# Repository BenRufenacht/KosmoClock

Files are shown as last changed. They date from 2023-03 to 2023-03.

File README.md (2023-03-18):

# KosmoClock
 Kosmo Format Clock Module based on LittleBen by Quinie 

 <p align="center">
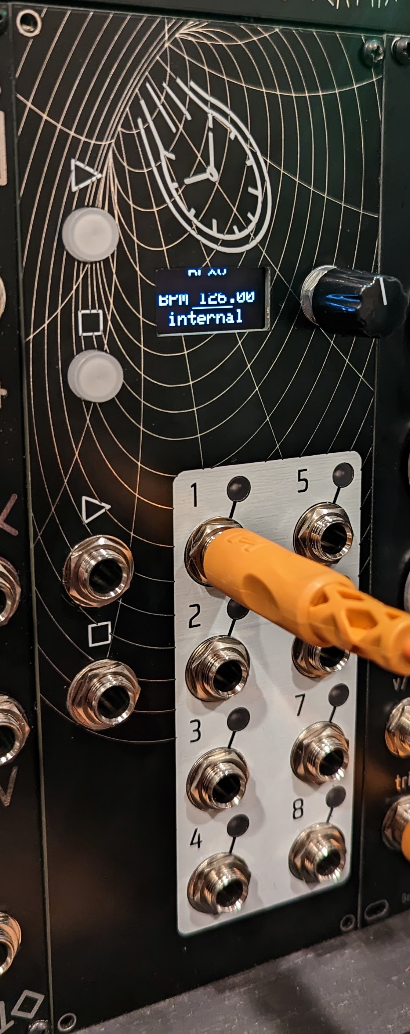
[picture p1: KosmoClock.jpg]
Kosmo Clock
  
</p>

Note that the UI varies significantly from Quinie's version.

Status:   
February 2023 - First run of manufacturing found some minor mistakes that were fixed, but the updates to the main board have not been tested.

License:  
[CC-BY-SA](https://creativecommons.org/licenses/by-sa/3.0/)

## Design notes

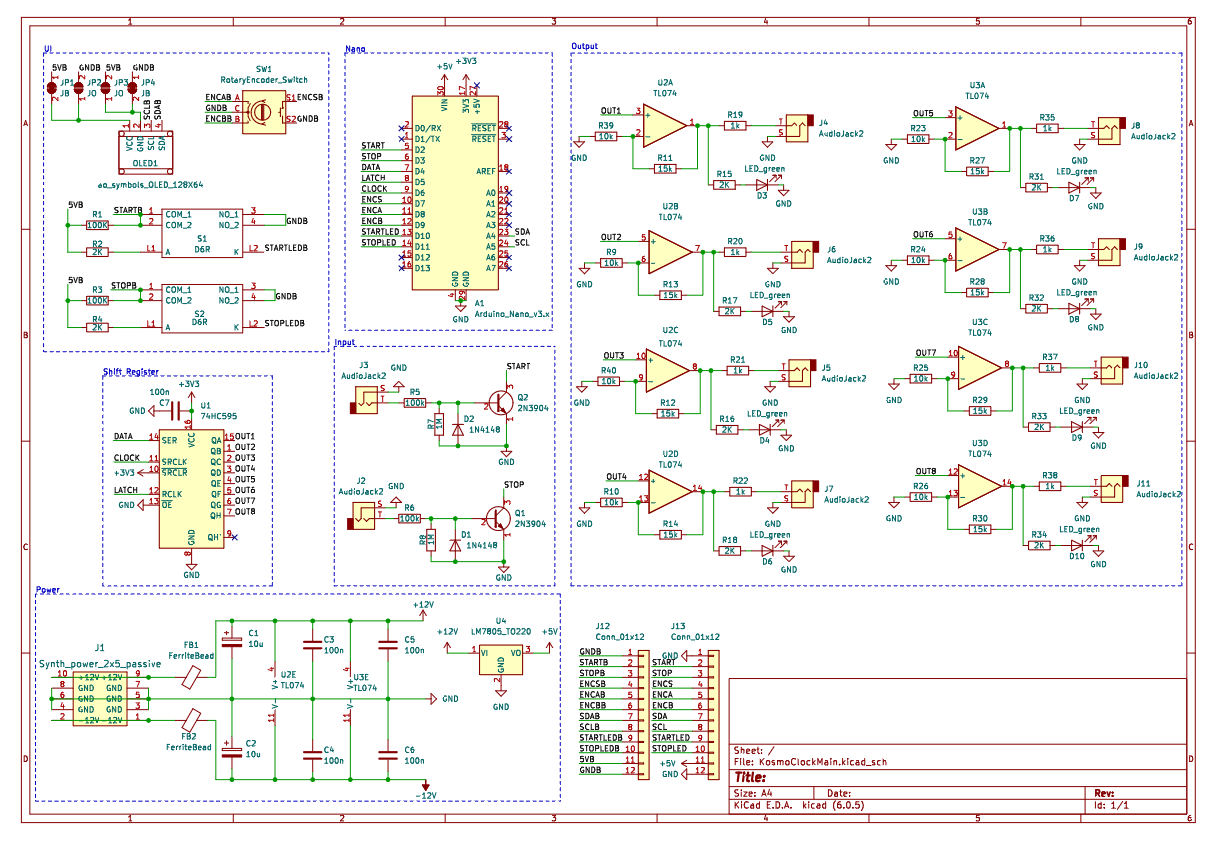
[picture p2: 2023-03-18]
ClockSchematics.png

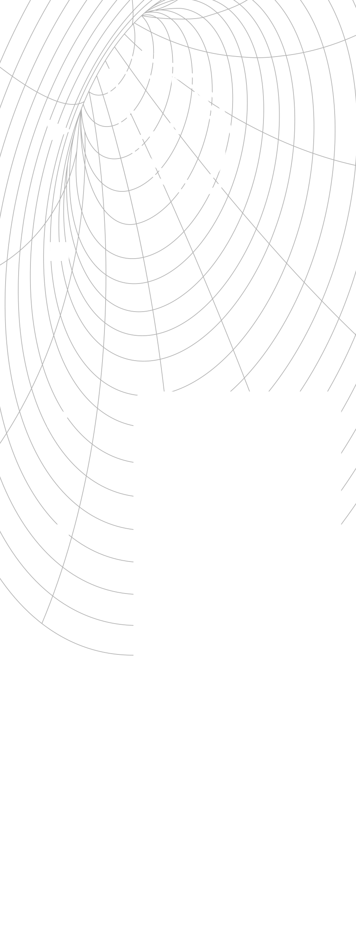
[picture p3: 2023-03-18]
ClockPanelTin.png

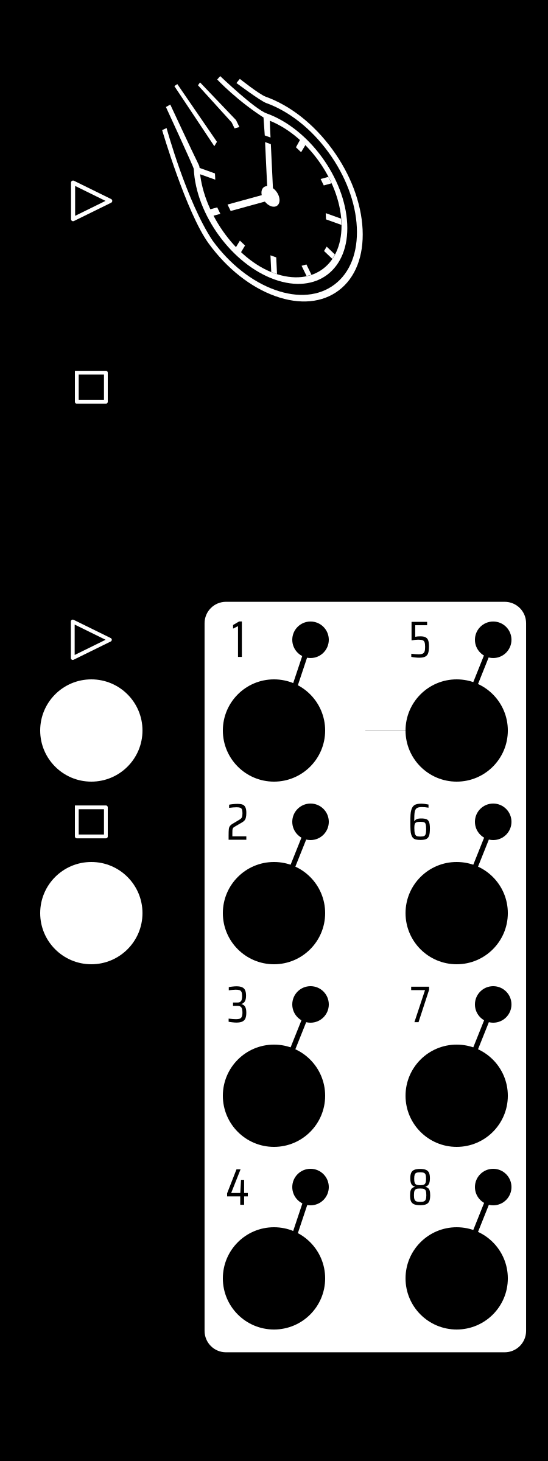
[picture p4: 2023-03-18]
ClockPanelSilkscreen.png

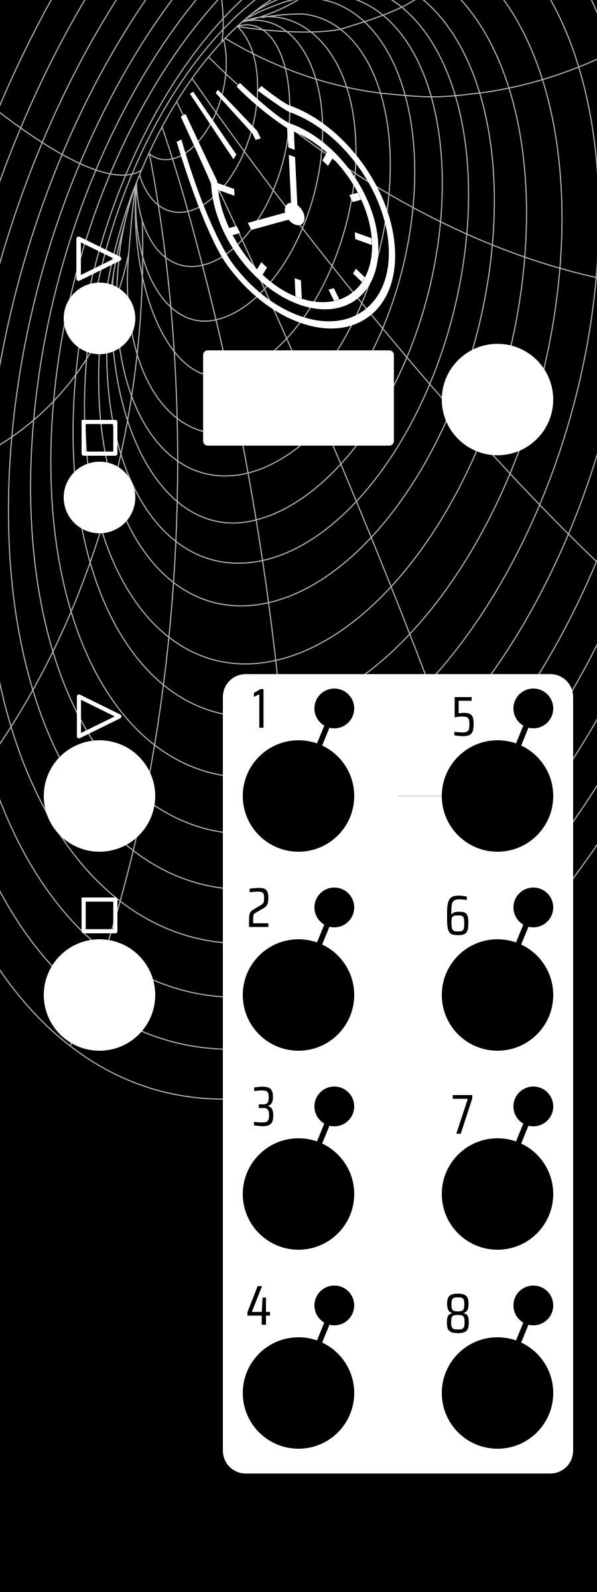
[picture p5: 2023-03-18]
ClockPanelGraphics.png

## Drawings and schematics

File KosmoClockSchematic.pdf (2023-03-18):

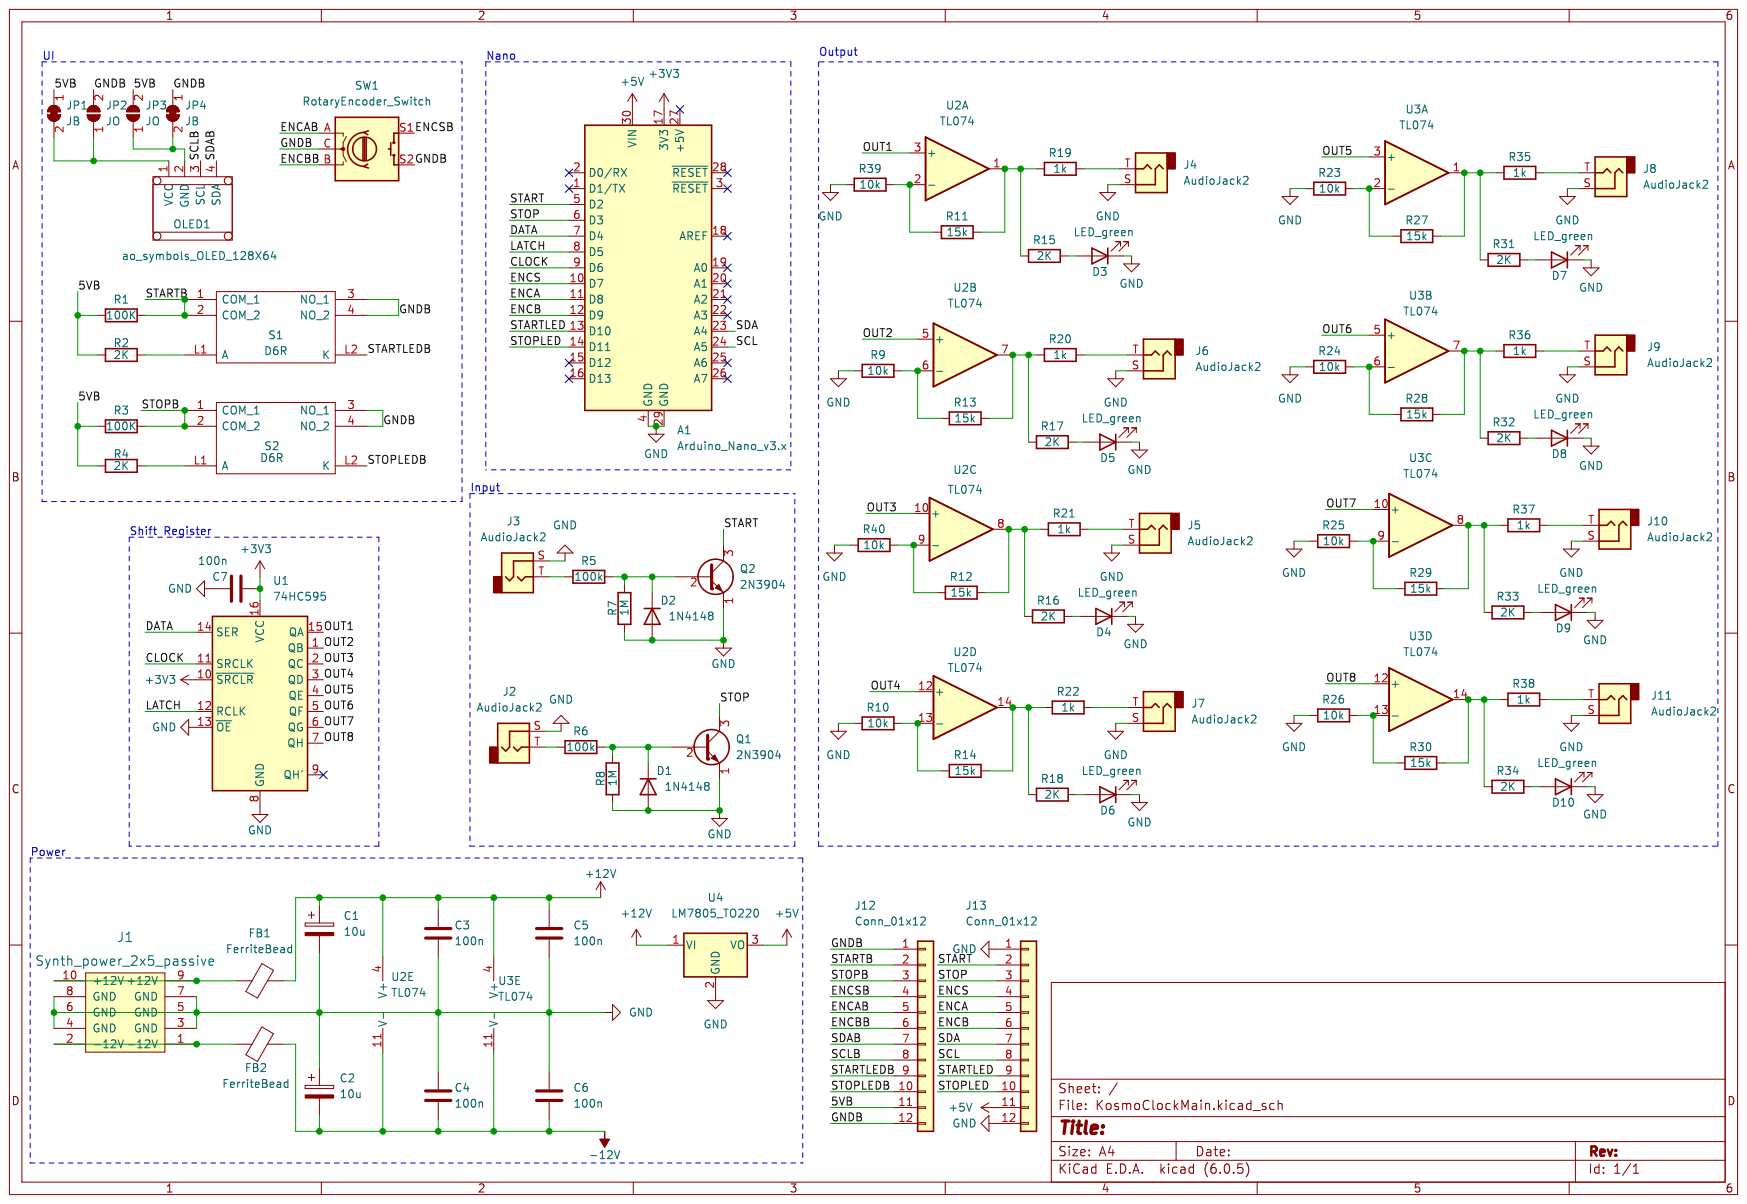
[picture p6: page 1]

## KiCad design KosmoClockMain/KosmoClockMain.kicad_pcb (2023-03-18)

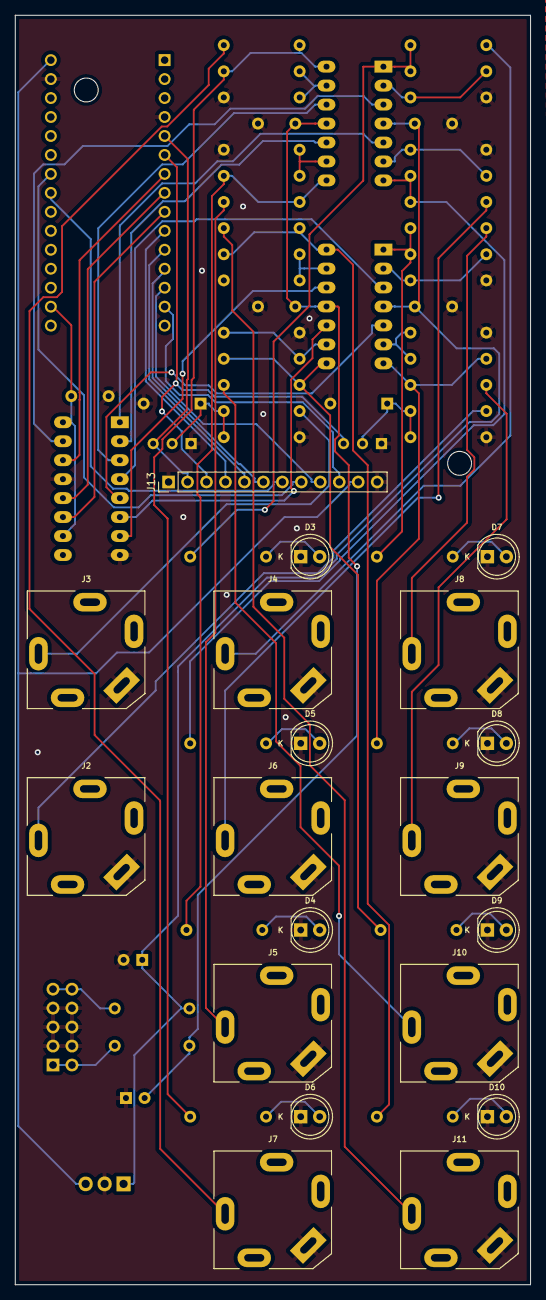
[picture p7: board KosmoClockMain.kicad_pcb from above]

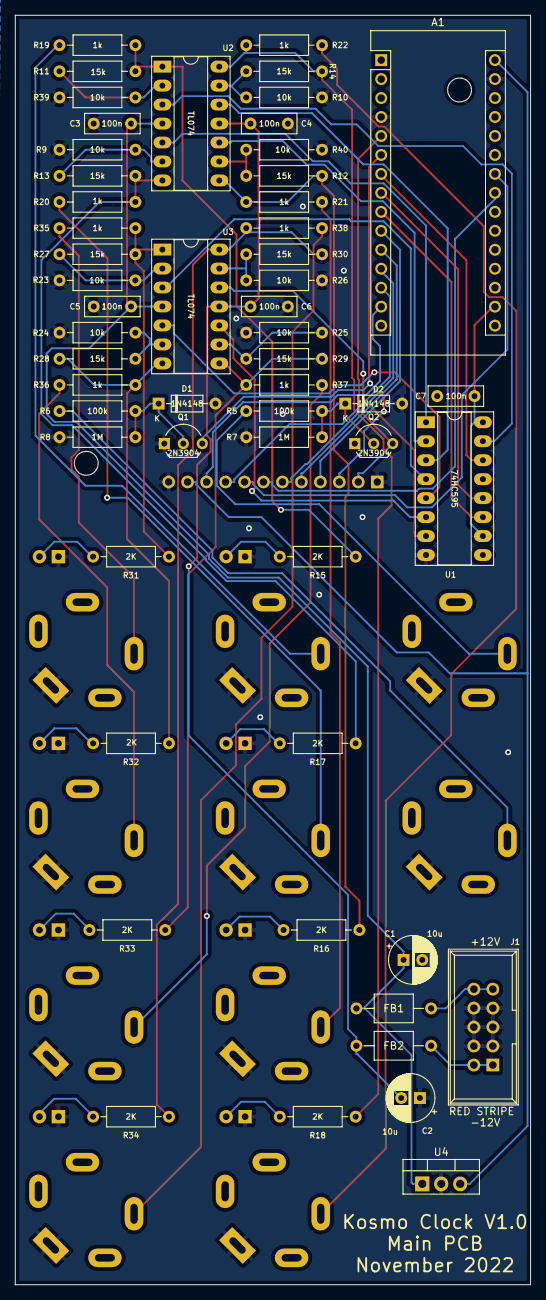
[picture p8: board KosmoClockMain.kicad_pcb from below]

Board: 2 copper layers, 69.0 x 170.0 mm, 74 parts (55 on the bottom side), 63 nets.

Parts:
A1: Arduino_Nano_v3.x; Arduino_Nano
C1, C2: 10u; CP_Radial_D6.3mm_P2.50mm
C3, C4, C5, C6, C7: 100n; C_Rect_L7.2mm_W2.5mm_P5.00mm_FKS2_FKP2_MKS2_MKP2
D1, D2: 1N4148; D_DO-35_SOD27_P7.62mm_Horizontal
D3, D4, D5, D6, D7, D8, D9, D10: LED_green; LED_D5.0mm
FB1, FB2: FerriteBead; L_Axial_L5.0mm_D3.6mm_P10.00mm_Horizontal_Murata_BL01RN1A2A2
J1: Synth_power_2x5_passive; Power_Header
J2, J3, J4, J5, J6, J7, J8, J9, J10, J11: AudioJack2; Jack_6.35mm_PJ_629HAN_slots
J13: Conn_01x12; PinHeader_1x12_P2.54mm_Vertical
Q1, Q2: 2N3904; TO-92_Inline_Wide
R5, R6: 100k; R_Axial_DIN0207_L6.3mm_D2.5mm_P10.16mm_Horizontal
R7, R8: 1M; R_Axial_DIN0207_L6.3mm_D2.5mm_P10.16mm_Horizontal
R9, R10, R23, R24, R25, R26, R39, R40: 10k; R_Axial_DIN0207_L6.3mm_D2.5mm_P10.16mm_Horizontal
R11, R12, R13, R14, R27, R28, R29, R30: 15k; R_Axial_DIN0207_L6.3mm_D2.5mm_P10.16mm_Horizontal
R15, R16, R17, R18, R31, R32, R33, R34: 2K; R_Axial_DIN0207_L6.3mm_D2.5mm_P10.16mm_Horizontal
R19, R20, R21, R22, R35, R36, R37, R38: 1k; R_Axial_DIN0207_L6.3mm_D2.5mm_P10.16mm_Horizontal
U1: 74HC595; DIP-16_W7.62mm_Socket_LongPads
U2, U3: TL074; DIP-14_W7.62mm_Socket_LongPads
U4: LM7805_TO220; TO-220-3_Vertical

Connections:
+3V3: A1.17 (3V3), C7.2, U1.10 (~SRCLR), U1.16 (VCC)
+5V: A1.30 (VIN), J13.11, U4.3 (VO)
+12V: C1.1, C3.1, C5.1, FB1.2, U2.4 (V+), U3.4 (V+), U4.1 (VI)
-12V: C2.2, C4.1, C6.1, FB2.2, U2.11 (V-), U3.11 (V-)
/CLOCK: A1.9 (D6), U1.11 (SRCLK)
/DATA: A1.7 (D4), U1.14 (SER)
/ENCA: A1.11 (D8), J13.5
/ENCB: A1.12 (D9), J13.6
/ENCS: A1.10 (D7), J13.4
/LATCH: A1.8 (D5), U1.12 (RCLK)
/OUT1: U1.15 (QA), U2.3 (+)
/OUT2: U1.1 (QB), U2.5 (+)
/OUT3: U1.2 (QC), U2.10 (+)
/OUT4: U1.3 (QD), U2.12 (+)
/OUT5: U1.4 (QE), U3.3 (+)
/OUT6: U1.5 (QF), U3.5 (+)
/OUT7: U1.6 (QG), U3.10 (+)
/OUT8: U1.7 (QH), U3.12 (+)
/SCL: A1.24 (A5), J13.8
/SDA: A1.23 (A4), J13.7
/START: A1.5 (D2), J13.2, Q2.3 (C)
/STARTLED: A1.13 (D10), J13.9
/STOP: A1.6 (D3), J13.3, Q1.3 (C)
/STOPLED: A1.14 (D11), J13.10
GND: A1.4 (GND), A1.29 (GND), C1.2, C2.1, C3.2, C4.2, C5.2, C6.2, C7.1, D1.2 (A), D2.2 (A), D3.1 (K), D4.1 (K), D5.1 (K), D6.1 (K), D7.1 (K), D8.1 (K), D9.1 (K), D10.1 (K), J1.3 (GND), J1.4 (GND), J1.5 (GND), J1.6 (GND), J1.7 (GND), J1.8 (GND), J2.S, J3.S, J4.S, J5.S, J6.S, J7.S, J8.S, J9.S, J10.S, J11.S, J13.1, J13.12, Q1.1 (E), Q2.1 (E), R7.2, R8.2, R9.1, R10.1, R23.1, R24.1, R25.1, R26.1, R39.1, R40.1, U1.8 (GND), U1.13 (~OE), U4.2 (GND)
unnamed: D1.1 (K), Q1.2 (B), R6.2, R8.1
unnamed: D2.1 (K), Q2.2 (B), R5.2, R7.1
unnamed: D3.2 (A), R15.2
unnamed: D4.2 (A), R16.2
unnamed: D5.2 (A), R17.2
unnamed: D6.2 (A), R18.2
unnamed: D7.2 (A), R31.2
unnamed: D8.2 (A), R32.2
unnamed: D9.2 (A), R33.2
unnamed: D10.2 (A), R34.2
unnamed: FB1.1, J1.9 (+12V), J1.10 (+12V)
unnamed: FB2.1, J1.1 (-12V), J1.2 (-12V)
unnamed: J2.T, R6.1
unnamed: J3.T, R5.1
unnamed: J4.T, R19.2
unnamed: J5.T, R21.2
unnamed: J6.T, R20.2
unnamed: J7.T, R22.2
unnamed: J8.T, R35.2
unnamed: J9.T, R36.2
unnamed: J10.T, R37.2
unnamed: J11.T, R38.2
unnamed: R10.2, R14.1, U2.13 (-)
unnamed: R11.1, R39.2, U2.2 (-)
unnamed: R11.2, R15.1, R19.1, U2.1
unnamed: R12.1, R40.2, U2.9 (-)
unnamed: R12.2, R16.1, R21.1, U2.8
unnamed: R9.2, R13.1, U2.6 (-)
unnamed: R13.2, R17.1, R20.1, U2.7
unnamed: R14.2, R18.1, R22.1, U2.14
unnamed: R23.2, R27.1, U3.2 (-)
unnamed: R24.2, R28.1, U3.6 (-)
unnamed: R25.2, R29.1, U3.9 (-)
unnamed: R26.2, R30.1, U3.13 (-)
unnamed: R27.2, R31.1, R35.1, U3.1
unnamed: R28.2, R32.1, R36.1, U3.7
unnamed: R29.2, R33.1, R37.1, U3.8
unnamed: R30.2, R34.1, R38.1, U3.14

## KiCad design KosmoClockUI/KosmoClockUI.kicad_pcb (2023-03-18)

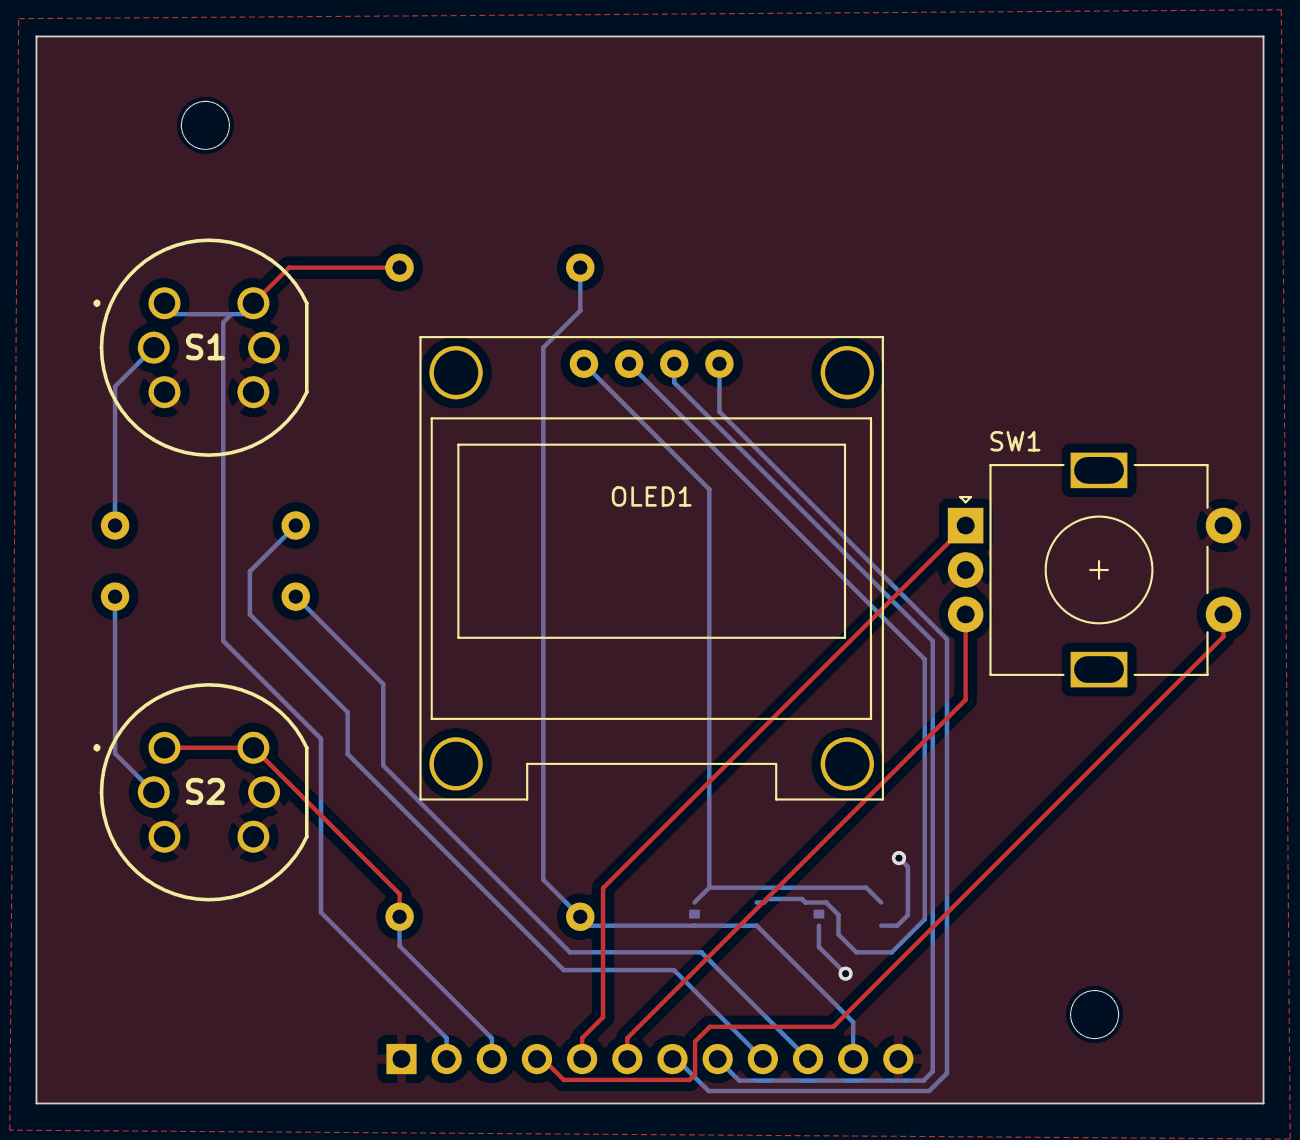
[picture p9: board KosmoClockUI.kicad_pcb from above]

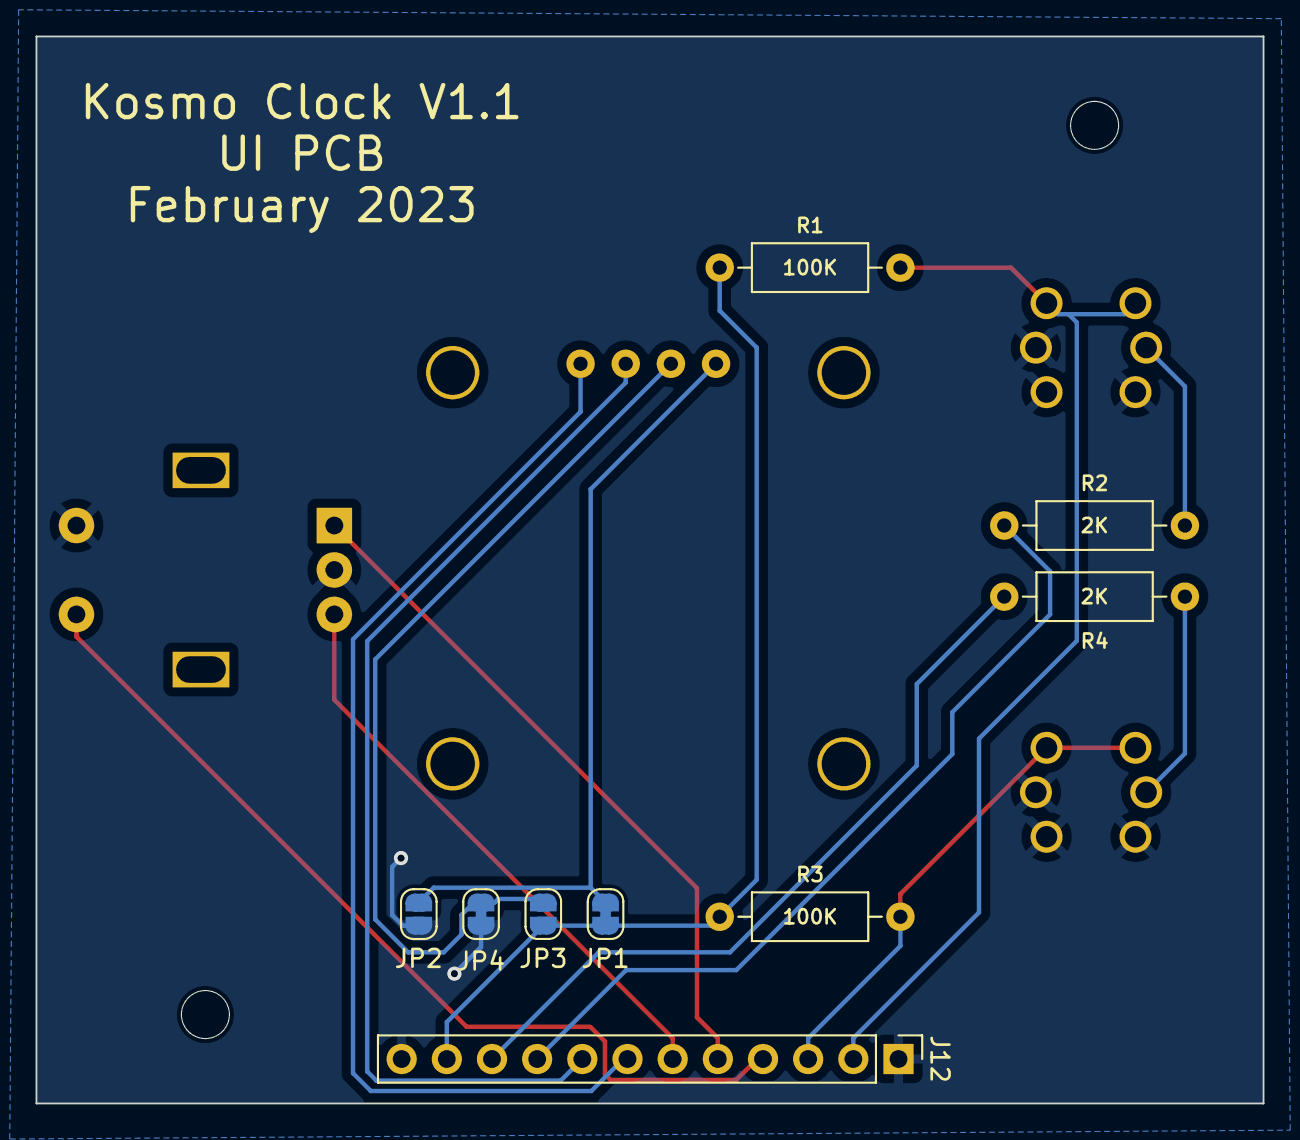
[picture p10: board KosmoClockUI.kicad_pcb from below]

Board: 2 copper layers, 69.0 x 60.0 mm, 13 parts (9 on the bottom side), 15 nets.

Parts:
J12: Conn_01x12; PinHeader_1x12_P2.54mm_Vertical
JP1, JP4: JB; SolderJumper-2_P1.3mm_Bridged_RoundedPad1.0x1.5mm
JP2, JP3: JO; SolderJumper-2_P1.3mm_Open_RoundedPad1.0x1.5mm
OLED1: ao_symbols_OLED_128X64; SSD1306_0.96_Oled
R1, R3: 100K; R_Axial_DIN0207_L6.3mm_D2.5mm_P10.16mm_Horizontal
R2, R4: 2K; R_Axial_DIN0207_L6.3mm_D2.5mm_P10.16mm_Horizontal
S1, S2: D6RLGNF1LFS
SW1: RotaryEncoder_Switch; RotaryEncoder_Alps_EC11E-Switch_Vertical_H20mm

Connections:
/5VB: J12.11, JP1.1 (A), JP3.2 (B), R1.1, R3.1
/ENCAB: J12.5, SW1.A
/ENCBB: J12.6, SW1.B
/ENCSB: J12.4, SW1.S1
/GNDB: J12.1, J12.12, JP2.2 (B), JP4.1 (A), S1.3 (NO_1), S1.4 (NO_2), S1.L2 (K), S2.3 (NO_1), S2.4 (NO_2), S2.L2 (K), SW1.C, SW1.S2
/SCLB: J12.8, OLED1.3 (SCL)
/SDAB: J12.7, OLED1.4 (SDA)
/STARTB: J12.2, R1.2, S1.1 (COM_1), S1.2 (COM_2)
/STARTLEDB: J12.9, R2.1
/STOPB: J12.3, R3.2, S2.1 (COM_1), S2.2 (COM_2)
/STOPLEDB: J12.10, R4.1
unnamed: JP1.2 (B), JP2.1 (A), OLED1.1 (VCC)
unnamed: JP3.1 (A), JP4.2 (B), OLED1.2 (GND)
unnamed: R2.2, S1.L1 (A)
unnamed: R4.2, S2.L1 (A)

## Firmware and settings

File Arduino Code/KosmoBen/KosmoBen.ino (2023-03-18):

/* 
 *  KosmoBen
 *  
 *  A master clock for Kosmo systems
 *  By: Ben Rufenacht
 *  Adapted From: Quinie.nl
 *  
 */

// Includes needed for running this code.
// TimerOne will handle the timing of the pulses

#include <TimerOne.h>  
#include <SPI.h>
#include <Wire.h>
#include <Adafruit_GFX.h>
#include <Adafruit_SSD1306.h>
#include <BasicEncoder.h>
#include <Bounce2.h>

#include "LittleBenOutputs.h"

int const maxLBOutput = 8;
// Load the outputs as class
LittleBenOutput LBOutputs[maxLBOutput] = {
  LittleBenOutput(0),
  LittleBenOutput(1),
  LittleBenOutput(2),
  LittleBenOutput(3),
  LittleBenOutput(4),
  LittleBenOutput(5),
  LittleBenOutput(6),
  LittleBenOutput(7)
};

byte selectedLBOutput = 0;

//Clock Settings
byte statusClock = 0; // 0 = stopped, 1 = playing, 2 = pause
byte clockSource = 1; // 0 = internal, 1 = external

long intervalMicroSeconds;  // variable for interval for timer running clock pulses calculted on BPM value

// These are used to output the clock on the 595 chip
// The bit are linked to the ouput as 2,4,6,8,1,3,5,7 <-- note: double check note sure
byte outputClockBits = B00000000; 

float bpm = 126;  // BPM value 
byte ppqn = 24; // Pulse per beat

#define startTriggerPin 2 // Start trigger pin
#define stopTriggerPin 3 // Stop trigger pin

// 595 output pins 
byte outputLatchPin = 5; 
byte outputClockPin = 6; 
byte outputDataPin = 4;  

// Rotary Encoder Inputs pins
#define inputCLK 9
#define inputDT 8
#define inputSW 7

BasicEncoder enc(inputCLK, inputDT);
Bounce2::Button SW = Bounce2::Button();

// Current en previous states of rotary pins
byte currentStateSW; 
byte previousStateSW;
byte currentStateEnc;
byte previousStateEnc; 

// Current menu item
byte menuItem = 0;

//Oled display settings
#define SCREEN_WIDTH 128 
#define SCREEN_HEIGHT 64
#define OLED_RESET     4 
#define SCREEN_ADDRESS 0x3C

int name;

bool updateScreen = false;
bool saving = false;
long savingtime;

Adafruit_SSD1306 display(SCREEN_WIDTH, SCREEN_HEIGHT, &Wire, OLED_RESET);

void setup() {

  // Set timer for internal clock
  Timer1.initialize(intervalMicroSeconds);
  Timer1.setPeriod(calculateIntervalMicroSecs());
  Timer1.attachInterrupt(ClockPulseInternal);
  
  attachInterrupt(digitalPinToInterrupt(stopTriggerPin), stopTrigger, FALLING );
  attachInterrupt(digitalPinToInterrupt(startTriggerPin), pauseTrigger, FALLING );

  // Set all the pins of 74HC595 as OUTPUT
  pinMode(outputLatchPin, OUTPUT);
  pinMode(outputDataPin, OUTPUT);  
  pinMode(outputClockPin, OUTPUT);

  // Rotary inputs
  SW.attach(inputSW, INPUT_PULLUP);
  SW.interval(10); 
  SW.setPressedState(LOW);
  
  // set state of rotary
  SW.update();
  previousStateSW = SW.pressed();
  previousStateEnc = enc.get_count();

  // Set Defaults
  SetDefaults();

  if(!display.begin(SSD1306_SWITCHCAPVCC, SCREEN_ADDRESS)) {
    //Serial.println(F("SSD1306 allocation failed"));
    for(;;); // Don't proceed, loop forever
  }
  
  display.clearDisplay(); 
  //display.dim(true);

  display.setTextSize(2);       
  display.setTextColor(SSD1306_WHITE);

  printScreenDefault();

}

void loop() {
  CheckRotarySwitch(); // Check Rotary Switch
  CheckRotary(); // Check Rotary 

  // Check is screen needs update
  if(updateScreen) { 
    // if menu is not 4 it is not the default menu
    if(menuItem <= 2) {
      printScreenDefault();
    } 
    else {
      printScreenOutputs();
    }
  updateScreen = false;
  }

  if(saving) { 
    long currentMillis = millis();
    if((currentMillis - savingtime) >= 2000) {
      saving = false;
    }
  }
}

void SetDefaults() {
  LBOutputs[6].SetclockDivider(3);
  LBOutputs[5].SetclockDivider(6);
  LBOutputs[4].SetclockDivider(12);
  LBOutputs[3].SetType(1);
  LBOutputs[2].SetType(1);
  LBOutputs[2].SetbeatCountDivider(2);
  LBOutputs[1].SetType(1);
  LBOutputs[1].SetbeatCountDivider(4);
  LBOutputs[0].SetType(1);
  LBOutputs[0].SetbeatCountDivider(8);
}

// Check if rotary switch has been pushed
// Set the menuState
void CheckRotarySwitch() {
   SW.update();
   currentStateSW = SW.pressed();
   if (currentStateSW != previousStateSW && currentStateSW == 0) {
      if(menuItem == 5) {
        menuItem = 0;
      } else {
        menuItem++;
      }
      updateScreen = true;
   }
   previousStateSW = currentStateSW; 
}

// Check if rotary is turned
// Update menu item
void CheckRotary() {
   enc.service();
   int changed = enc.get_change();
   if (changed){  
     currentStateEnc = enc.get_count(); 
    switch(menuItem) {
      case 0:     
        UpdateBPM();
        break;
      case 1:
        UpdateBPMDecimal();
        break;
      case 2:
        UpdateClockSource();
        break;
      case 3:
        UpdateOutputSelector();
        break;
      case 4:
        UpdateOutputType();         
        break;
      case 5:
        UpdateOutputTypeValue();         
        break;
     }
   } 
   previousStateEnc = currentStateEnc;  
}

// Rotary updates BPM 
void UpdateBPM() {
  if(clockSource == 0) { // only update if clock is internal
    if (currentStateEnc > previousStateEnc)
    {
      bpm++;
    }
    else
    {
      bpm--;
    }
    updateTimer();
    updateScreen = true;
  }
}

// Updates BPM Decimal
void UpdateBPMDecimal() {
  if(clockSource == 0) { // only update if clock is internal
    if (currentStateEnc > previousStateEnc)
    {
      bpm += 0.1;
    }
    else
    {
      bpm -= 0.1;
    }
    updateTimer();
    updateScreen = true;
  }
}

// Update the type of clock
void UpdateClockSource() {
   clockSource = !clockSource;
   updateScreen = true;
}

void UpdateOutputSelector() {
  int tmp = selectedLBOutput; // integer temp value for calulations and suppressing bufferoverflow of bytes
   if (currentStateEnc > previousStateEnc) { 
     tmp++; 
   } else {
     tmp--;
   }
   
   if(tmp < 0) {
      selectedLBOutput = 7;
   } else if(tmp >= 8) {
      selectedLBOutput = 0;
   } else {
      selectedLBOutput = tmp;
   }
   updateScreen = true;
}

void UpdateOutputType() {
  if (currentStateEnc > previousStateEnc) { 
     LBOutputs[selectedLBOutput].SetType(1); // add 1
   } else {
     LBOutputs[selectedLBOutput].SetType(-1);
   }
   updateScreen = true;
}

void UpdateOutputTypeValue() {
  if (currentStateEnc > previousStateEnc) { 
     LBOutputs[selectedLBOutput].SetTypeValue(1); // add 1
   } else {
     LBOutputs[selectedLBOutput].SetTypeValue(-1);
   }
   updateScreen = true;
}

void UpdateSettings() {
  saving = true;
  updateScreen = true;
  savingtime = millis();
}

// Update the timer
void updateTimer() {
  Timer1.setPeriod(calculateIntervalMicroSecs());
}

// Clock comes from internal
void ClockPulseInternal() {
  // Check Clock for play state and internal
  if((statusClock == 1) && (clockSource == 0) ){ 
    ClockPulse();
  }
}

// Clock pulse comes from outside
void ClockPulseOuter() {
  ClockPulse();
}

void ClockPulse() {
  // run thru outputs
  for (int i = 0; i < maxLBOutput; i++) {
    LBOutputs[i].Pulse(ppqn); // Call pulse function on outputs
    bitWrite(outputClockBits, i, LBOutputs[i].GetOutputBit()); // set the output byte based on output settings
  }
  
  //output
  outputClock(outputClockBits);
  delay(4);
  outputClock(B00000000);
}


// Output the clock
void outputClock(byte pins)
{
   digitalWrite(outputLatchPin, LOW);
   shiftOut(outputDataPin, outputClockPin, LSBFIRST, pins);
   digitalWrite(outputLatchPin, HIGH);
}

// Stop the clock
void stopTrigger() {
  if(clockSource == 0){ 
    statusClock = 0;
    updateScreen = true;
  }
  // Loop thru outputs
  for (int i = 0; i < maxLBOutput; i++) {
    LBOutputs[i].resetCounters(); // Reset Counters
  }
}

// Input pulse on pause button/jack
// Pause the clock or other function depending on the clock source setting of Littleben
void pauseTrigger() {
  if(clockSource == 0){ 
    togglePauseOrPlay();
  }
  if(clockSource == 1){ 
    ClockPulseOuter();
  }
}

void togglePauseOrPlay(){
  if(statusClock == 1){ 
    statusClock = 2;
  } else {
    statusClock = 1;
  } 
  updateScreen = true;
}

long calculateIntervalMicroSecs() {
  return 60L * 1000 * 1000 / bpm / ppqn;
}

//Prints the clock status to the screen
void printScreenStatus() {
    display.setCursor(40,2);    
    display.setTextSize(2);   
    if (statusClock == 0) {
      display.print("STOP");
    }  
    else if (statusClock == 1) {
      display.print("PLAY");
    }
    else {
      display.print("PAUSE");
    }

    display.setCursor(14, 46);    
    display.setTextSize(2); 
    if (clockSource == 0) {
      display.print("internal");
    }  
    else {
      display.print("external");
    }
}

// prints the BPM to the screen
void printScreenBPM() {
    display.setCursor(4, 24);
    display.setTextSize(2);  
    // Internal BPM
    if(clockSource == 0){ 
      display.print("BPM ");
      if(bpm<100){
          display.print(F(" "));
      } 
      display.print(bpm);
    }
    if(clockSource == 1){ 
      display.print("---.--");
    }
}

void printScreenMenuSelection() {
    switch(menuItem) {
      case 0: //Clock
        display.drawFastHLine(44, 42, 50, WHITE); // BPM
        break;
      case 1:
        display.drawFastHLine(90, 42, 38, WHITE); // BPM Decimal
        break;
      case 2:
        display.drawFastHLine(12, 62, 100, WHITE); // ClockSource
        break;
      case 3:
        display.drawFastHLine(2, 32, 20, WHITE); // OutputName, Output selector
        break;
      case 4:
        display.drawFastHLine(30, 18, 70, WHITE); // OutputType, Clock, Beat, Random
        break;
      case 5:
        display.drawFastHLine(2, 44, 100, WHITE); // OutputType Value
        break;
    }
}

// Print the display 
void printScreenDefault() {
    display.clearDisplay();
  
    printScreenStatus();
    printScreenBPM();
    printScreenMenuSelection();

    display.display();
}

void printScreenOutputs() {
    display.clearDisplay(); 
    printScreenOutputName();
    printScreenOutputType();
    printScreenOutputTypeValue();
    printScreenMenuSelection();
    display.display();
}

void printScreenOutputName() {
    display.setCursor(2, 2);    
    display.setTextSize(4);      
    display.print(LBOutputs[selectedLBOutput].GetName()); 
}

void printScreenOutputType() {
    display.setCursor(30, 2);    
    display.setTextSize(2);      
    display.print(LBOutputs[selectedLBOutput].GetTypeName()); 
}

void printScreenOutputTypeValue() {
    display.setCursor(2, 35);    
    display.setTextSize(1);      
    display.print(LBOutputs[selectedLBOutput].GetTypeValueText()); 
}
